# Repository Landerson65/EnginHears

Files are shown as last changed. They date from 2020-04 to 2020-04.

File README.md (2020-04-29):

# EnginHears
LCBC Hearing Aid Development Platform

This project intended to develop a low cost, socially destigmatized hearing aid design. Despite hearing loss being so prominent, the average cost of hearing aids is $2,300 per unit, putting hearing aids out of reach of many low- to middle-income families. In addition, many people who need and can afford hearing aids choose not to buy them, as their bulky aesthetic increases social stigma. To combat these current market limitations, the EnginHears developed a Low Cost Bone Conduction (LCBC) Hearing Aid Development Platform.

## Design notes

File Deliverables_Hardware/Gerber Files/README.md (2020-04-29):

This folder contains all of the necessary files in order
to have the hardware system printed circuit board manufactured. 
This includes drill files, copper layers, silkscreen layers,
board profile and more. These gerber files were created using Autodesk Eagle.

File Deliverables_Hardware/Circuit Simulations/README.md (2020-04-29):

This directory contains files describing the proposed analog filter implementations as well as their simulated magnitude plots. 
In addition, plots of the magnitude responses of the transduction components are also included.

Schematics of the proposed analog circuit are available in the Schematics directory.
Plots of the magnitude responses of the proposed analog filter networks, and transduction components are included in the plots directory

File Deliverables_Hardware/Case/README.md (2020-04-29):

This folder contains 3D design files for the LCBC case assembly.

All of the 3D SolidWorks files for the 9th Iteration of the case assembly are in this directory.
Mechanical drawings of the CAD files for the 9th Iteration are in the Drawings directory
STL files necessary to recreate the 9th iteration of the case assembly (ready for 3D printing) are available in the STL directory.

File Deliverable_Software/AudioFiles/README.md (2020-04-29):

EnginHears
LCBC Hearing Aid Development Platform

In this folder you can find audio files used to test the effectiveness
of the ski-slope filter

_Filtered is added to files post-filtering
and
_50 indicates the max gain was set to 50

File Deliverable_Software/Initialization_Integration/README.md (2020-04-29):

This folder only included the main C file used to test the initializations 
for the microcontroller. It contains a simple notch filter that filters out signal noise.
This is the file that was run in the demo of 
hardware and software integration. To run this file, replace 'watchdog_cpu01.c' 
with this file in the 
Microcontroller_IO folder. They require the same additional libraries.

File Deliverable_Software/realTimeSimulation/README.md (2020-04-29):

This folder contains the MATLAB simulation for real-time filtering applications. 
This simulation was mainly used for debugging purposes as a way to test noise, but
it does show the filter applied in real-time.

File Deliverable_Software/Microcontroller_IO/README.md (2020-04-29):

This folder houses the initialization code needed to make the microcontroller operational.

'watchdog_cpu01.c' is the main file that has the I/O initializations and the general layout
for the filter implementation. The gain calculation is included in this file, but requires
the addition of an FFT/iFFT and DMA to be operational.

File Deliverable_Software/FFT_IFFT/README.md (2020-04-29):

This folder contains the Visual Studio Project Solution that includes the modular C functions.

Example implementations of an FFT, iFFT, and ski-slope filter 
are demonstrated and output to the console.

The example input data was selected because they had known FFT values,
ensuring the FFT algorith operated correctly.

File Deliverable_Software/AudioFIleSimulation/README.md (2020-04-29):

This is a MATLAB simulation that demonstrates adding the ski-slope filtering algorithm 
on conversations that simulate hearing loss.

The file 'enginHearDemo.m' is the main file to run the simulation.
The conversations pre- and post- filtering will be played aloud.

Several graphs analyzing the characteristics of the signal will be output for analysis.

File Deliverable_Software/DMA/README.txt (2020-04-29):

DMA Setup
Team: EnginHears 
Project: Low-Cost Bone-Conduction Hearing Aid
4/29/2020

There are multiple files associated with this project, which have been consolidated into 3 sets

1.  adc_soc_continuous_dma_cpu01.c
2.  buffdac_sine_dma_cpu01.c
3.  DMA_custom_setup.c

**HOW TO RUN*******************************************************************

To run, open up the adc_soc_continuous_dma folder in Code Composer Studio with target device 
TMS320F28377S selected. The main file to run is adc_soc_continuous_dma_cpu01.c.

**CURRENT STATUS**************************************************************

Due to COVID-19 and the lack of F28377s microcontrollers, the DMA setup has not been tested. This document
discusses relevent example files to set up DMA, as well as the final desired set-up below.

The team wants DMA to conduct ACD and DAC via the hardware. 
The peripheral interrupt trigger source is ADCAINT1.
Set up PIE for DMA (PIE INT 7.1)
There will be 3 buffers that are length 128 samples.
The buffers will be used to store ADC samples, filter computations, and DAC output.
The buffers will rotate location in the dmaISR.

**NEXT STEPS******************************************************************

1. Edit the adc_soc_continuous_dma to have the following characteristics
       -Fs = 25,000 Hz
       -Buffer size 128
       -Remove initialization associated with ADC Interrupt and EPWM source
       -Use the DMA_custom_setup.c values as desired reference

2. Once this is working, integrate it into the LOCO BOCO initialization files to get ADC
   working and buffers rotating in the dmaISR.

3. Extend DMA to work on the DAC, using the previous DMA initialization and buffdac_sine_dma_cpu01.c
   as reference.

**adc_soc_continuous_dma_cpu01.c**********************************************

An example script from C2000Ware with supporting folder files that sets up two ADC channels to convert simultaneously. The
results will be transferred by the DMA into a buffer in RAM.

This file contains the desired DMA initialization as well as dmaISR and memory storage.

**buffdac_sine_dma_cpu01.c****************************************************

An example script from C2000Ware with supporting folder files that generates a sine wave on the buffered DAC output using the DMA 
to transfer sine values stored in a sine table in GSRAM to DACVALS, DACOUTA/ADCINA0.

This script is for DAC initialization reference only. However, try to follow the adc_soc_continuous_dma.c format whenever possible.

**DMA_custom_setup.c*********************************************************

This file does not compile. These HAL variable values are for reference only for desired final values.

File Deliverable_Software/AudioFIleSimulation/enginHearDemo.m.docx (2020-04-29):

% EnginHears Version 2.0

%{

I'm calling this version 2.0 even though there was no official version

1.0. I'm treating the algorithm that changed the frequency spectru in

a specific band as version 1.0. Version 2.0 uses the ski-slope filter

that we found online in hearingAidF.m. If a nother significant change

to the algorithm occurs, we'll call that Version 3.0 and so on. Version

2.0 also includes other functions: createPowerSpectrum, viewAudio, and

controlVolume.

%}

%% x = original audio signal

%% Fs = sample rate in Hertz

%% L = number of samples

%% X = the fft of x

%% transitionV = a vector of 4 frequencies used for the calcualtion of the ski-slope filter in freqshape

%% gain = input gainused for the max value in freqshape

%% Xleft_editted = is a variable used to make the application of the filter easier

%% Xright_editted = is a variable used to make the application of the filter easier

%% y = the ifft of the X after the filter is applied

clear; close all;

%% Read and Play Audio File

[x, Fs] = audioread('Conversation-Moderate.mp3');

player = audioplayer( controlVolume(x,1), Fs);

play(player)

pause(50)

%% Take the FFT of the input signal x

X = fft(x);

%% From MATLAB: create Power Spectrum

createPowerSpectrum(X, Fs, ' X')

%% Calculate and Apply Ski-Slope Filter

transitionV = [1000, 1500, 2550, 5000];

g = 50;

[~, gain] = freqshape(x, g, transitionV, Fs); % freqshape claims to adjust

% the signal for you, but the output is not changed noticeably, so I have

%elected to apply the filter manually

Xleft_editted = X(:,1).*gain;

Xright_editted = X(:,2).*gain;

X_editted = cat(2,Xleft_editted,Xright_editted);

%% take the ifft of the editted X signal

y = ifft(X_editted,'symmetric');

%%write to mps file

audiowrite('Conversation_Moderate_Filtered_50.wav', y, Fs);

%% create audio players for the signals

%play player2 for new sample

player2 = audioplayer(controlVolume(y, 1), Fs);

play(player2)

%%

viewAudio(x,Fs,' Conversation')

viewAudio(y,Fs,' Editted Conversation')

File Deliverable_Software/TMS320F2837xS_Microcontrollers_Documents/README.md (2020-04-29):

This folder contains the TMS320F2837xS Microcontrollers datasheet 
For more information on the board visit: 

https://www.ti.com/product/TMS320F28377S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

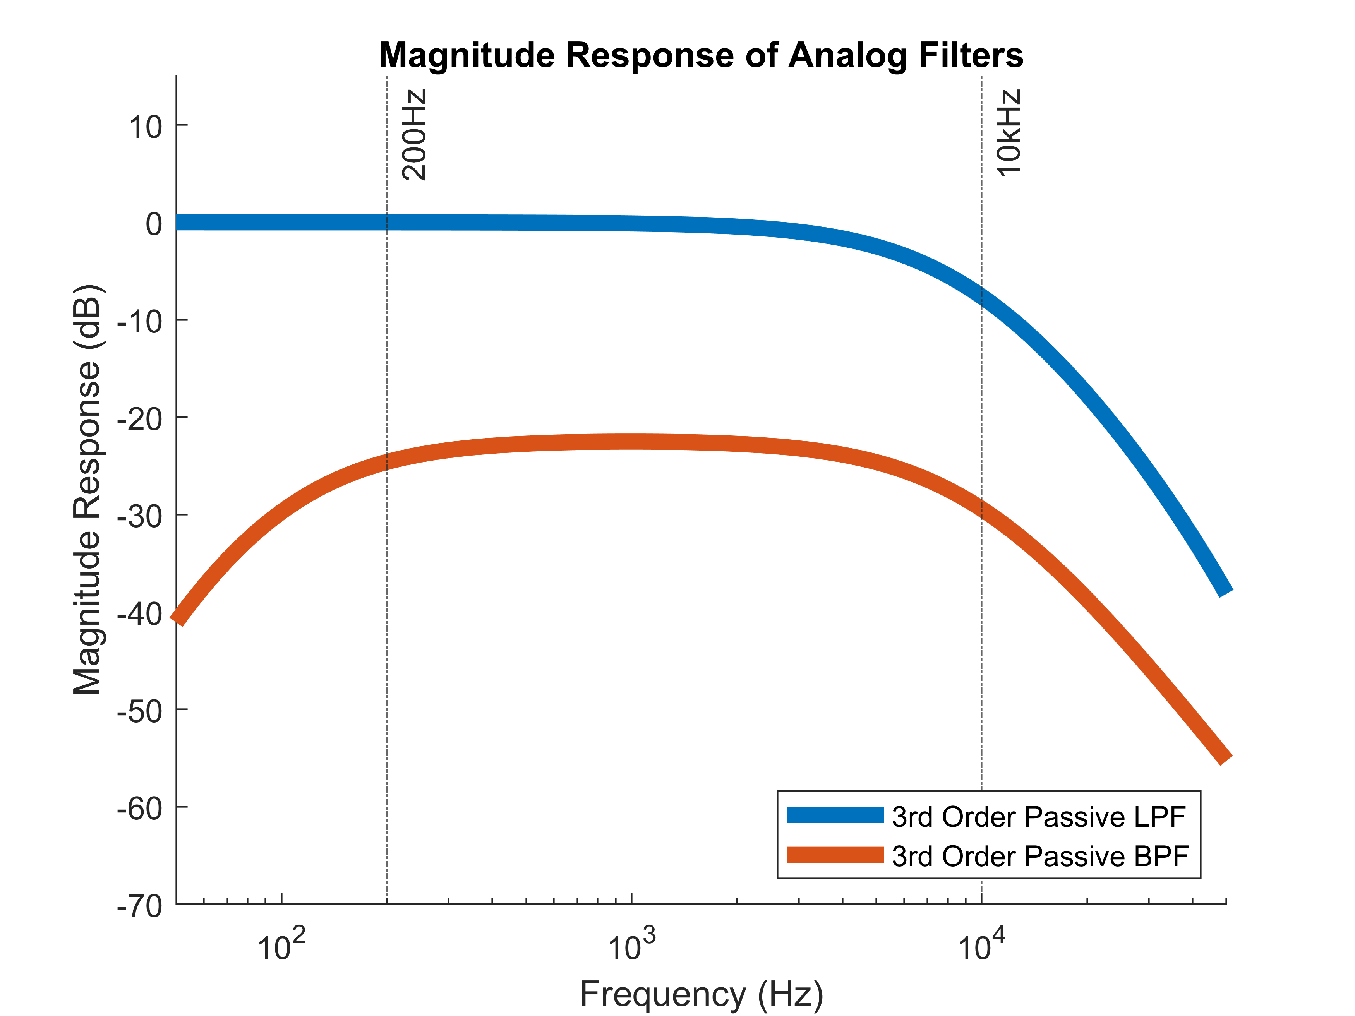
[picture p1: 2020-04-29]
Deliverables_Hardware/Circuit Simulations/Plots/analog_filter_magnitude_plot.png

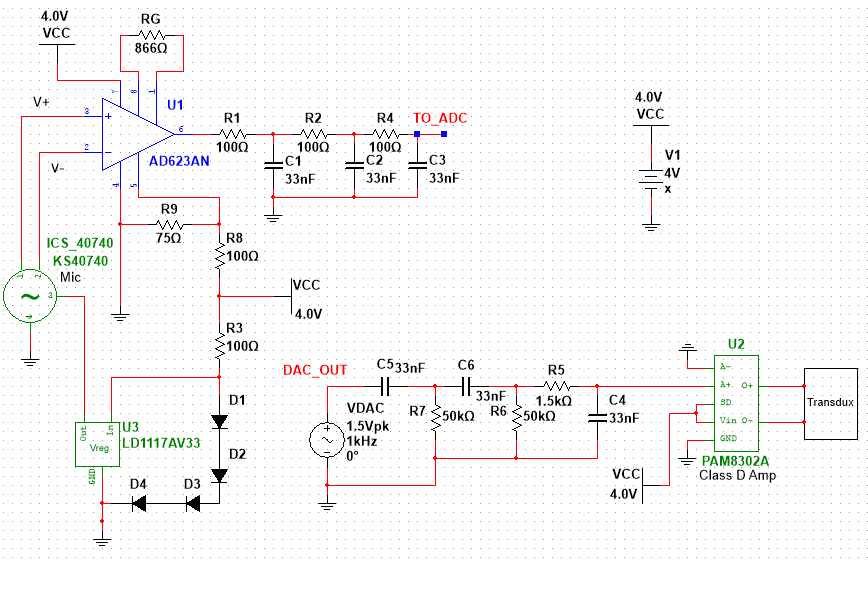
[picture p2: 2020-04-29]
Deliverables_Hardware/Circuit Simulations/Schematics/locoboco_analog_schematic.png

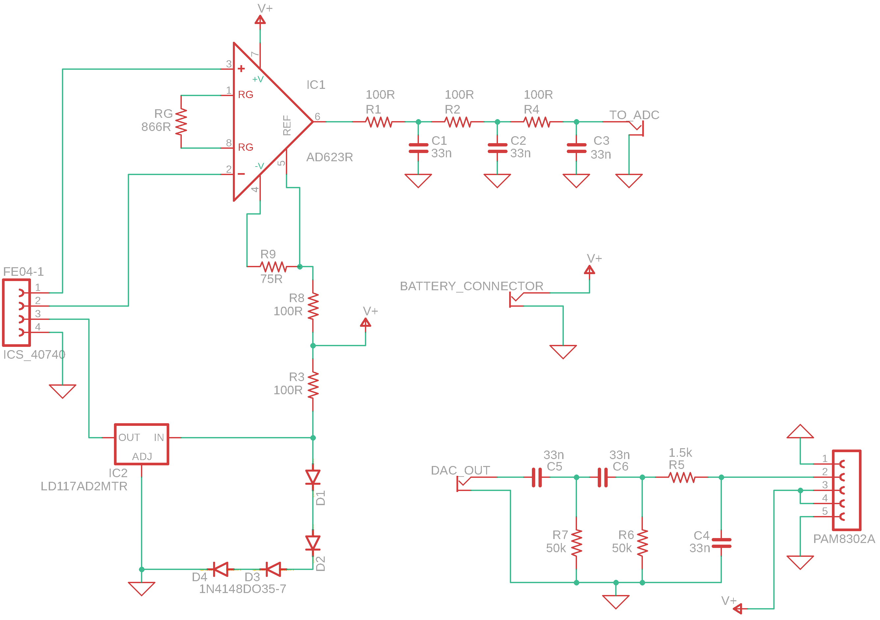
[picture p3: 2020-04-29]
Deliverables_Hardware/Gerber Files/Layout Image/Analog_Schematic.png

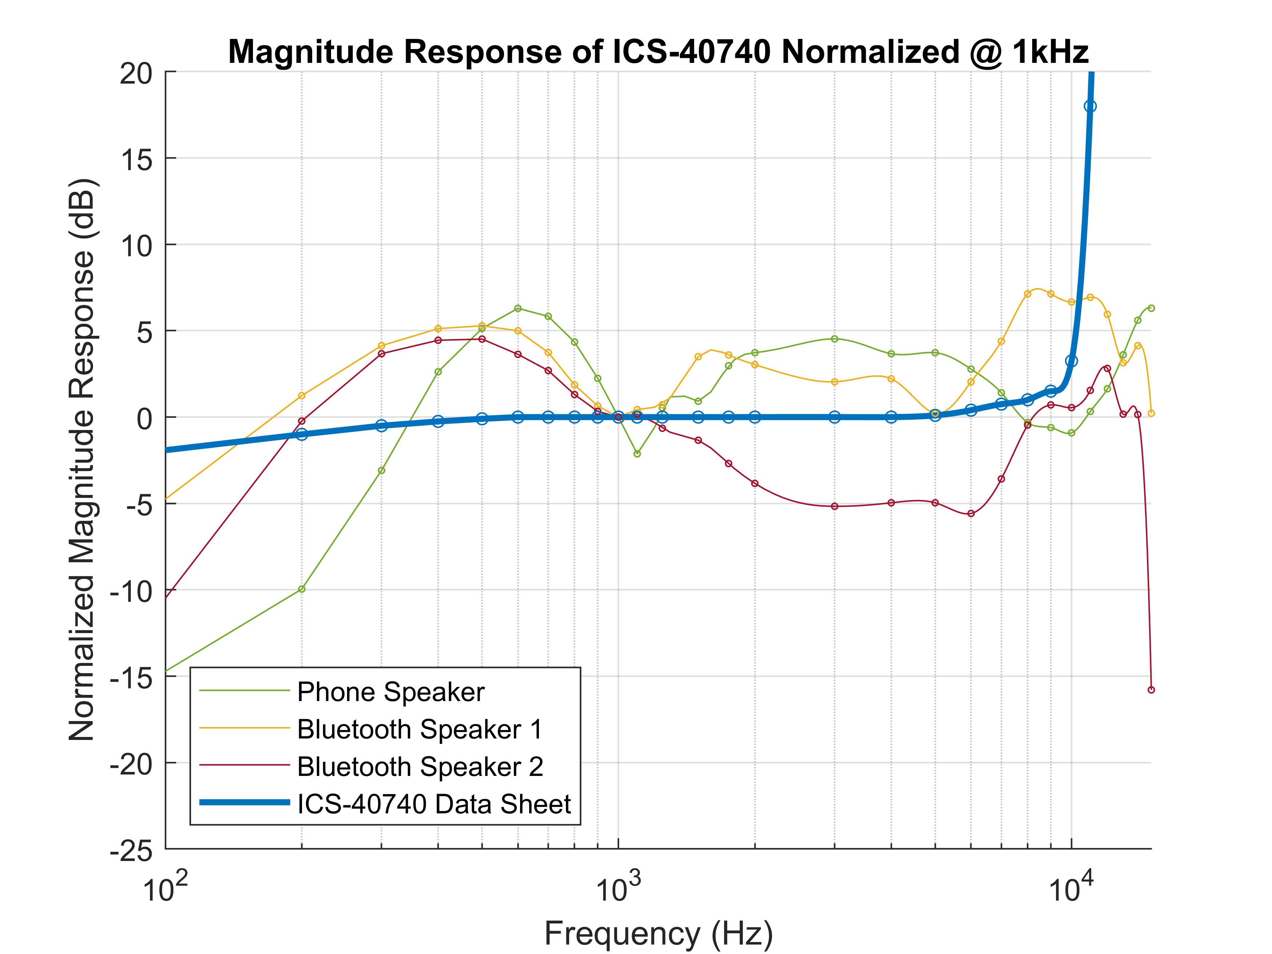
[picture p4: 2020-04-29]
Deliverables_Hardware/Circuit Simulations/Plots/ics-40740_magnitude_response.png

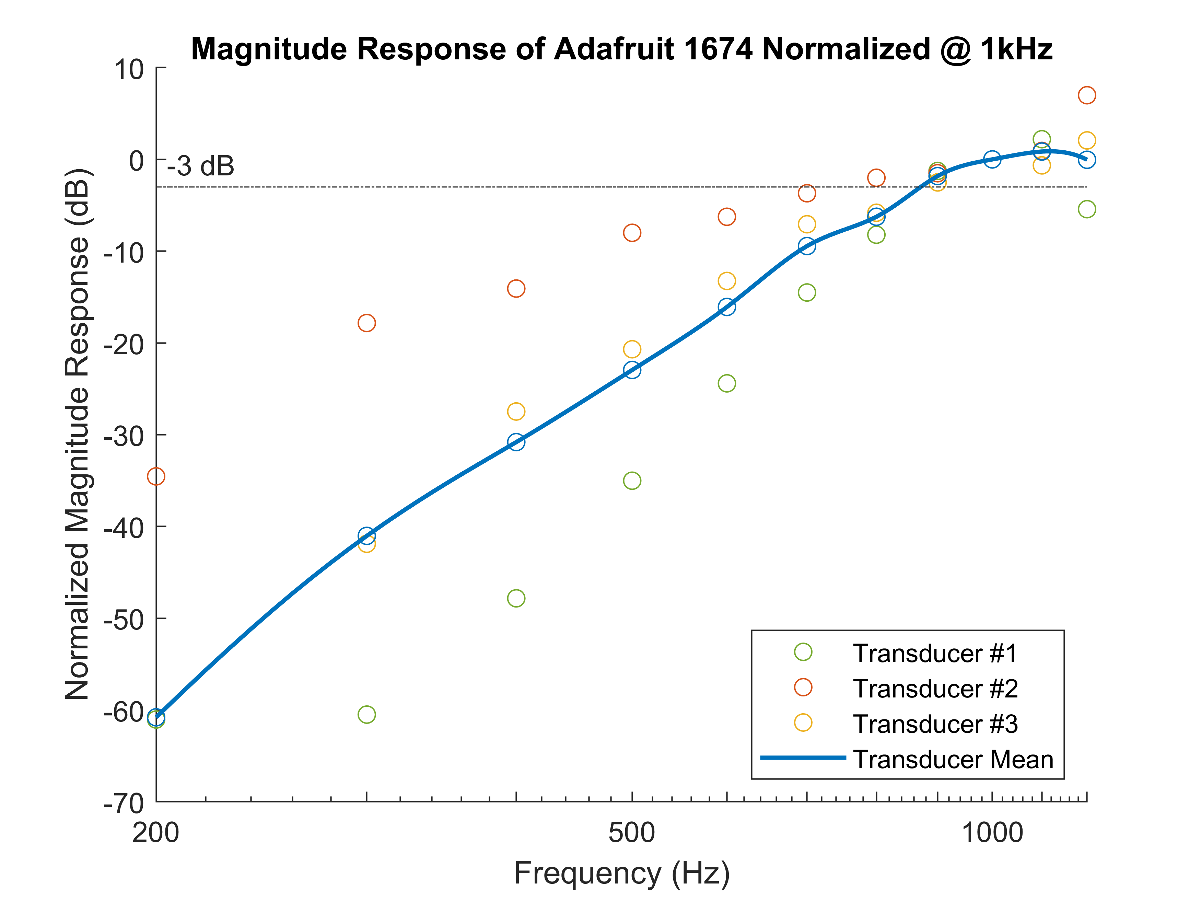
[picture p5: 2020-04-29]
Deliverables_Hardware/Circuit Simulations/Plots/adafruit_1674_bc_transdux_normalized_magnitude_plot.png

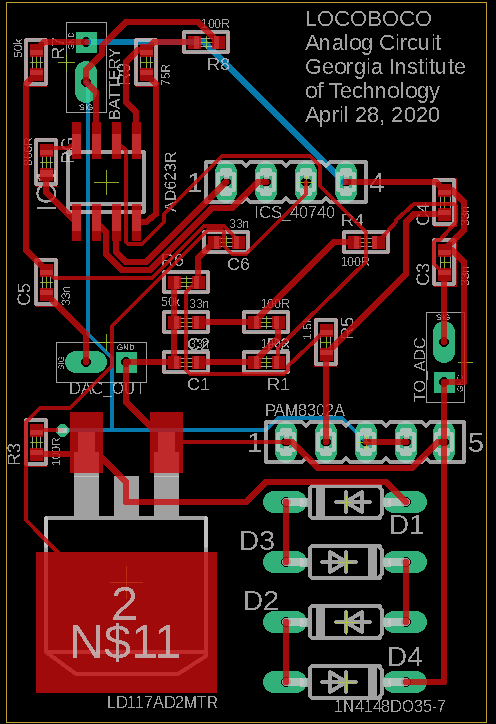
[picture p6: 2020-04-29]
Deliverables_Hardware/Gerber Files/Layout Image/Analog_Circuit_Layout.png

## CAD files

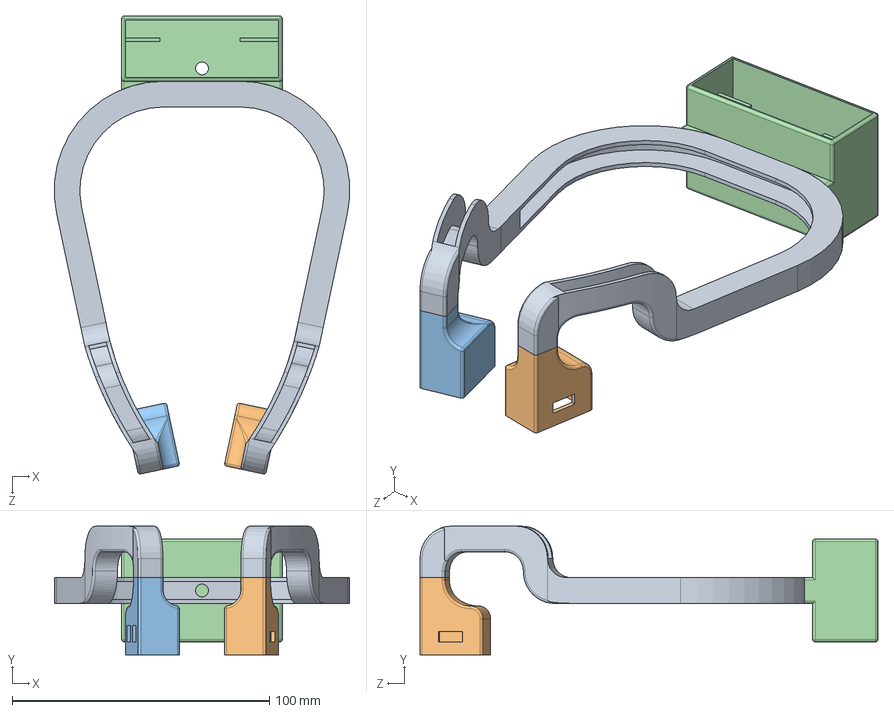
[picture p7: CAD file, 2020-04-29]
Deliverables_Hardware/Case/combined-case-it9.SLDASM
114.8 x 50.0 x 178.1 mm
head-band-it9
transdux-left-it9
transdux-right-it9
elex-compartment-it9

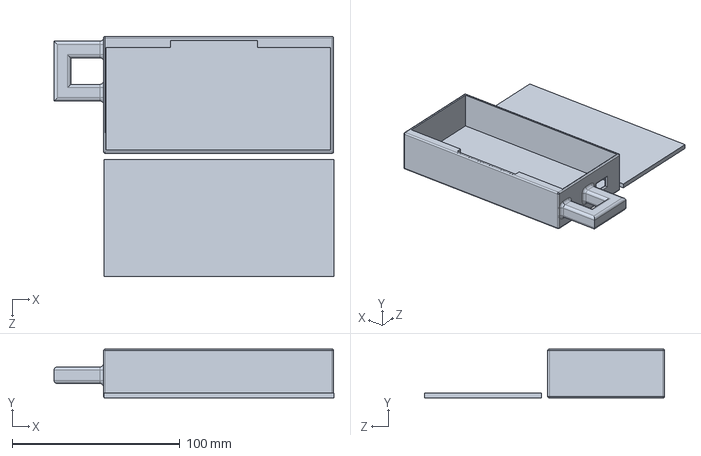
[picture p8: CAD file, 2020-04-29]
Deliverables_Hardware/Case/Box_Belt_Hook_v2.SLDPRT
166.7 x 29.1 x 143.1 mm

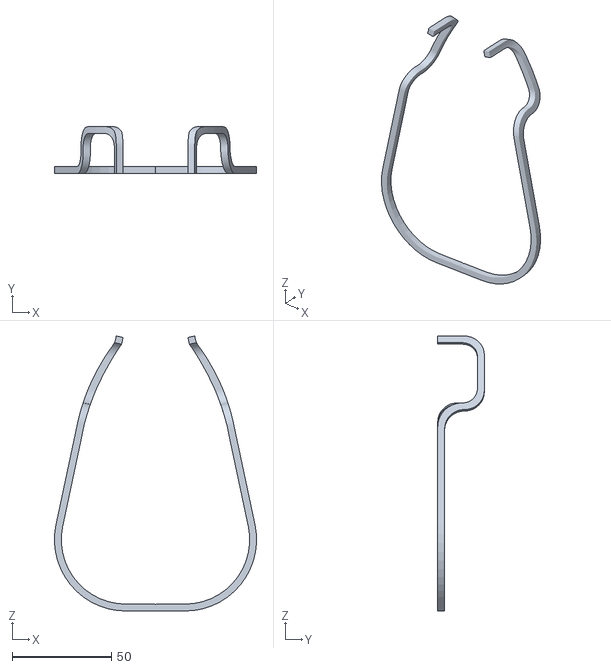
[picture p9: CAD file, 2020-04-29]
Deliverables_Hardware/Case/STL/compression-band-it8_ABS.STL
101.9 x 23.5 x 138.7

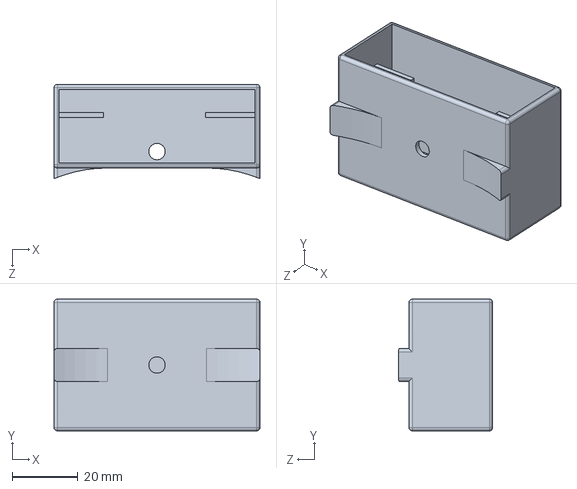
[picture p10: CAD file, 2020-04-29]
Deliverables_Hardware/Case/elex-compartment-it9.SLDPRT
62.5 x 40.0 x 28.6 mm

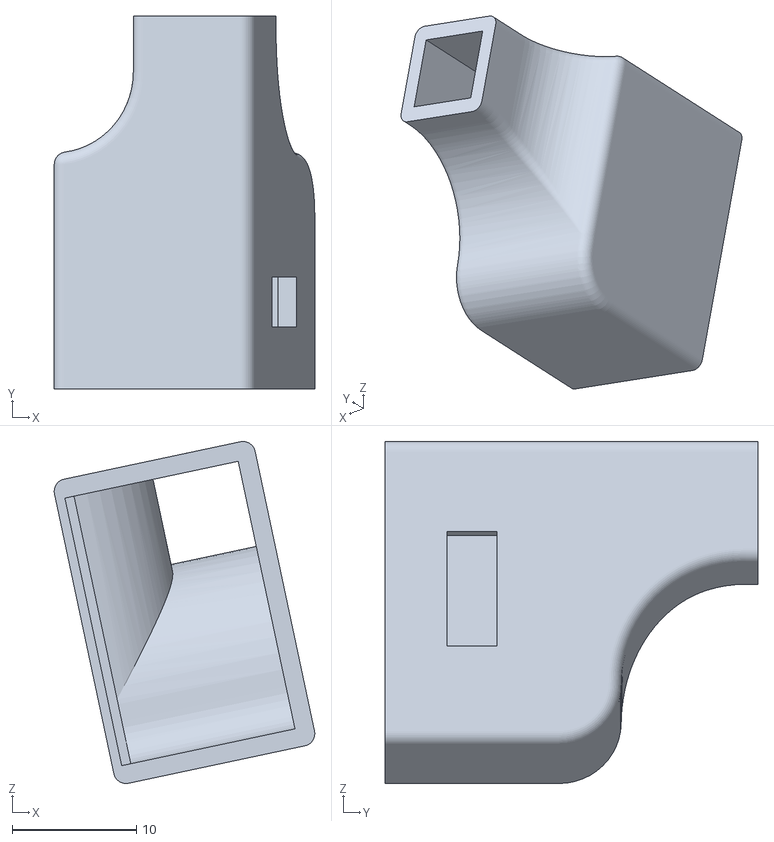
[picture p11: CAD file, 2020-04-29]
Deliverables_Hardware/Case/STL/transdux-left-it9_TPU.STL
21.0 x 30.0 x 27.5

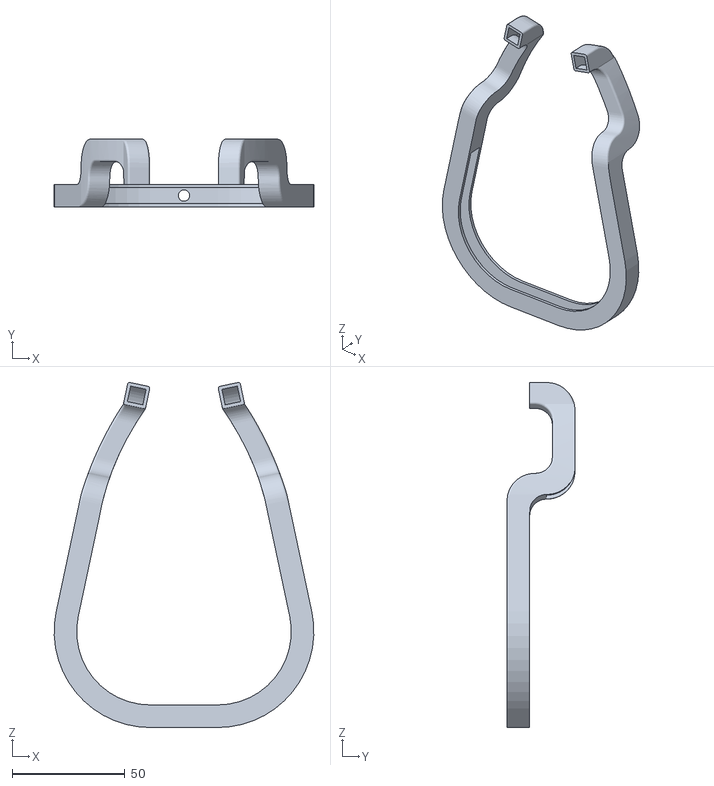
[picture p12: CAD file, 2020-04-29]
Deliverables_Hardware/Case/STL/head-band-it9_TPU.STL
114.9 x 30.0 x 152.7

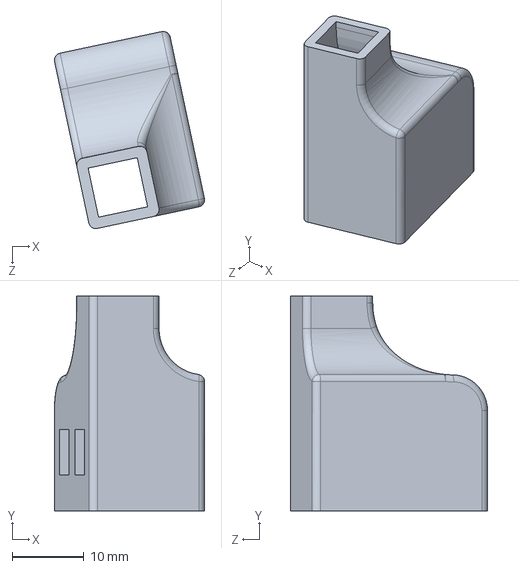
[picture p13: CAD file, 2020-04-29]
Deliverables_Hardware/Case/transdux-right-it9.SLDPRT
21.0 x 30.0 x 27.5 mm

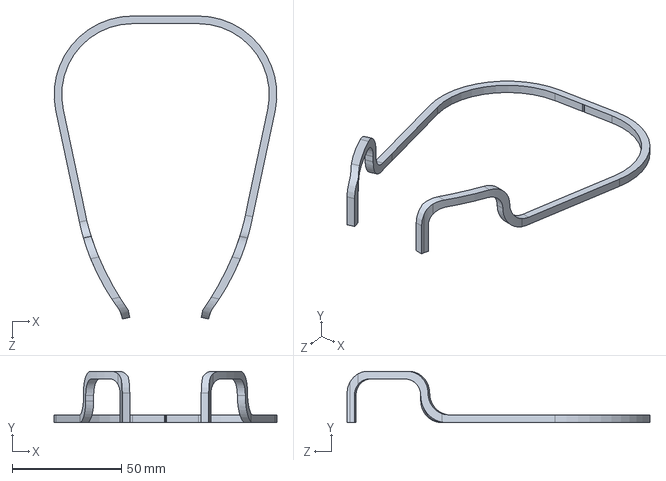
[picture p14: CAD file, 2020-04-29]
Deliverables_Hardware/Case/compression-band-it8.SLDPRT
101.9 x 23.5 x 138.7 mm

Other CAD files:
Deliverable_Software/Microcontroller_IO/cpu01/ccs/CPU1_RAM/F2837xS_Gpio.obj
Deliverable_Software/Microcontroller_IO/cpu01/ccs/CPU1_RAM/F2837xS_SysCtrl.obj
Deliverables_Hardware/Case/STL/elex-compartment-it9_ABS.STL
Deliverable_Software/Microcontroller_IO/cpu01/ccs/CPU1_RAM/watchdog_cpu01.obj
Deliverable_Software/Microcontroller_IO/cpu01/ccs/CPU1_RAM/DelayUs.obj
Deliverable_Software/Microcontroller_IO/cpu01/ccs/CPU1_RAM/F2837xS_CodeStartBranch.obj
Deliverables_Hardware/Case/STL/transdux-right-it9_TPU.STL
Deliverable_Software/Microcontroller_IO/cpu01/ccs/CPU1_RAM/F2837xS_PieCtrl.obj
Deliverables_Hardware/Case/transdux-left-it9.SLDPRT
Deliverable_Software/Microcontroller_IO/cpu01/ccs/CPU1_RAM/F2837xS_usDelay.obj
Deliverable_Software/Microcontroller_IO/cpu01/ccs/CPU1_RAM/F2837xS_DefaultISR.obj
Deliverable_Software/Microcontroller_IO/cpu01/ccs/CPU1_RAM/F2837xS_GlobalVariableDefs.obj
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

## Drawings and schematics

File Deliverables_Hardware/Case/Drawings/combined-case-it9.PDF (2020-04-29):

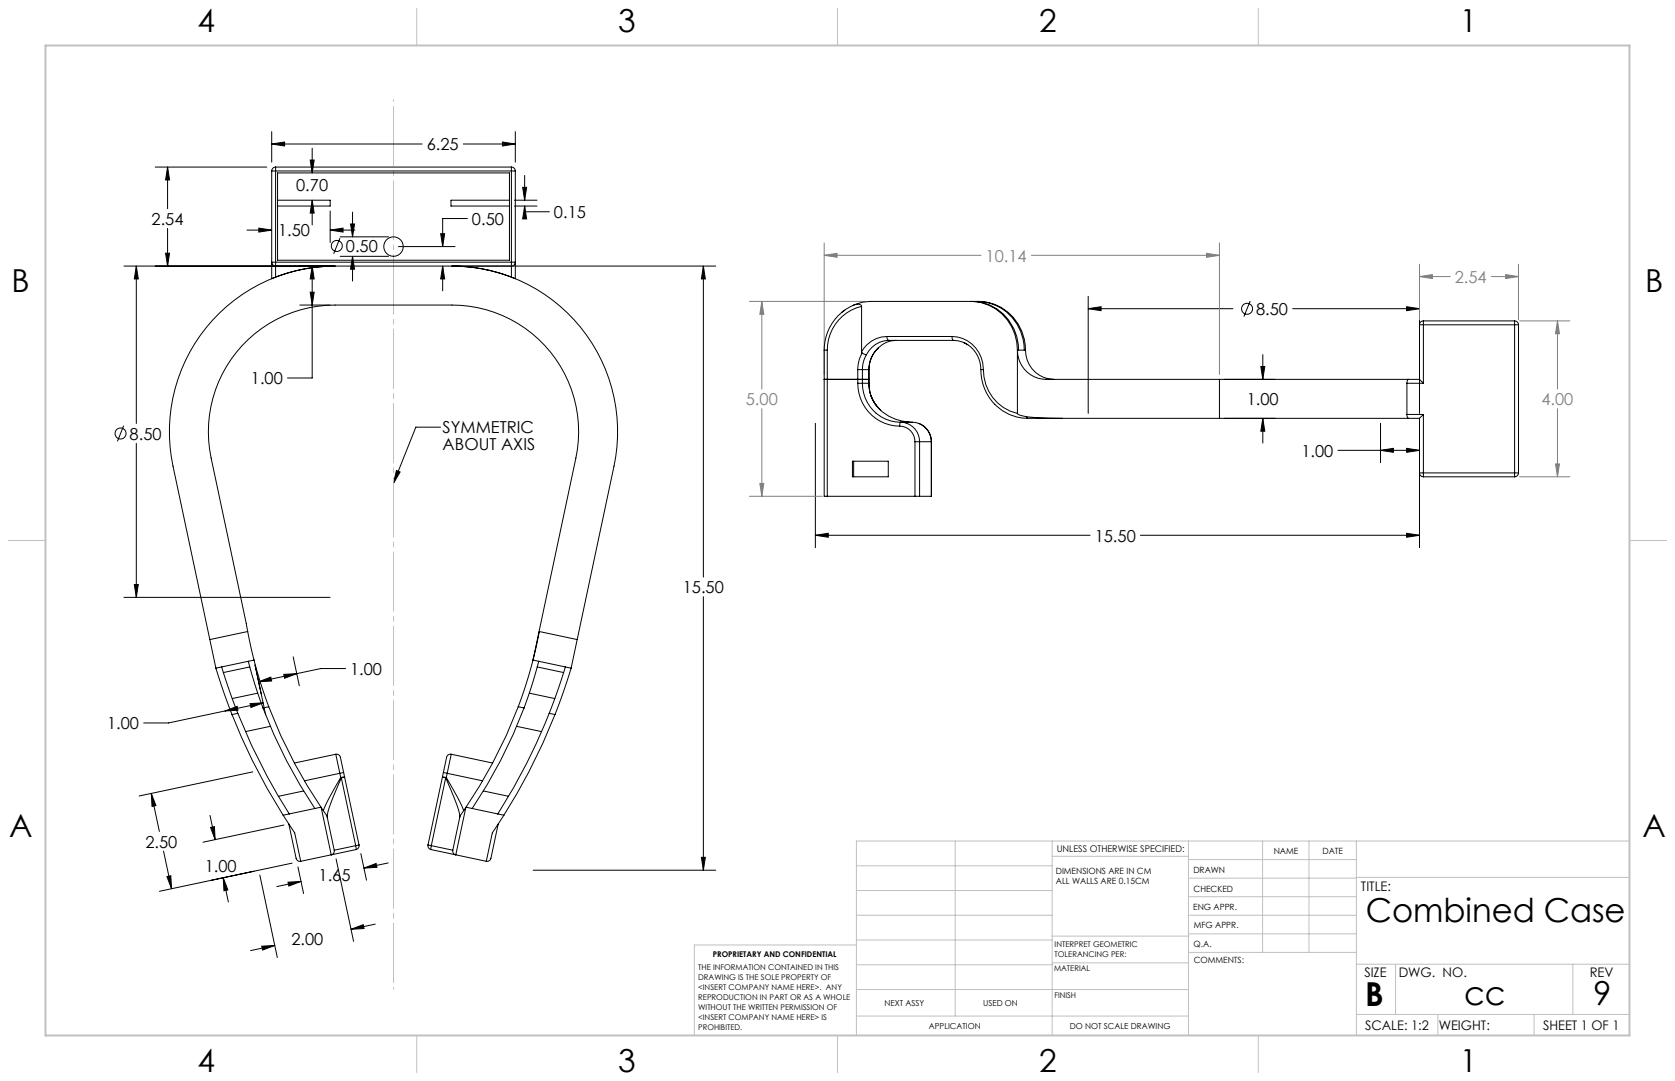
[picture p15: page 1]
ABOUT AXIS

UNLESS OTHERWISE SPECIFIED: | | NAME | DATE
DIMENSIONS ARE IN CM ALL WALLS ARE 0.15CM | DRAWN

CHECKED | | | TITLE: Combined Case

ENG APPR.
MFG APPR.

INTERPRET GEOMETRIC TOLERANCING PER: | Q.A.
MATERIAL | | SIZE B | DWG. NO. cc | REV 9

PROPRIETARY AND CONFIDENTIAL
THE INFORMATION CONTAINED IN THIS
DRAWING IS THE SOLE PROPERTY OF
<INSERT COMPANY NAME HERE>. ANY
REPRODUCTION IN PART OR AS A WHOLE
WITHOUT THE WRITTEN PERMISSION OF
<INSERT COMPANY NAME HERE> IS
PROHIBITED.

NEXT ASSY | USED ON | FINISH

APPLICATION | DO NOT SCALE DRAWING | | SCALE: 1:2 | WEIGHT: | SHEET 1 OF 1

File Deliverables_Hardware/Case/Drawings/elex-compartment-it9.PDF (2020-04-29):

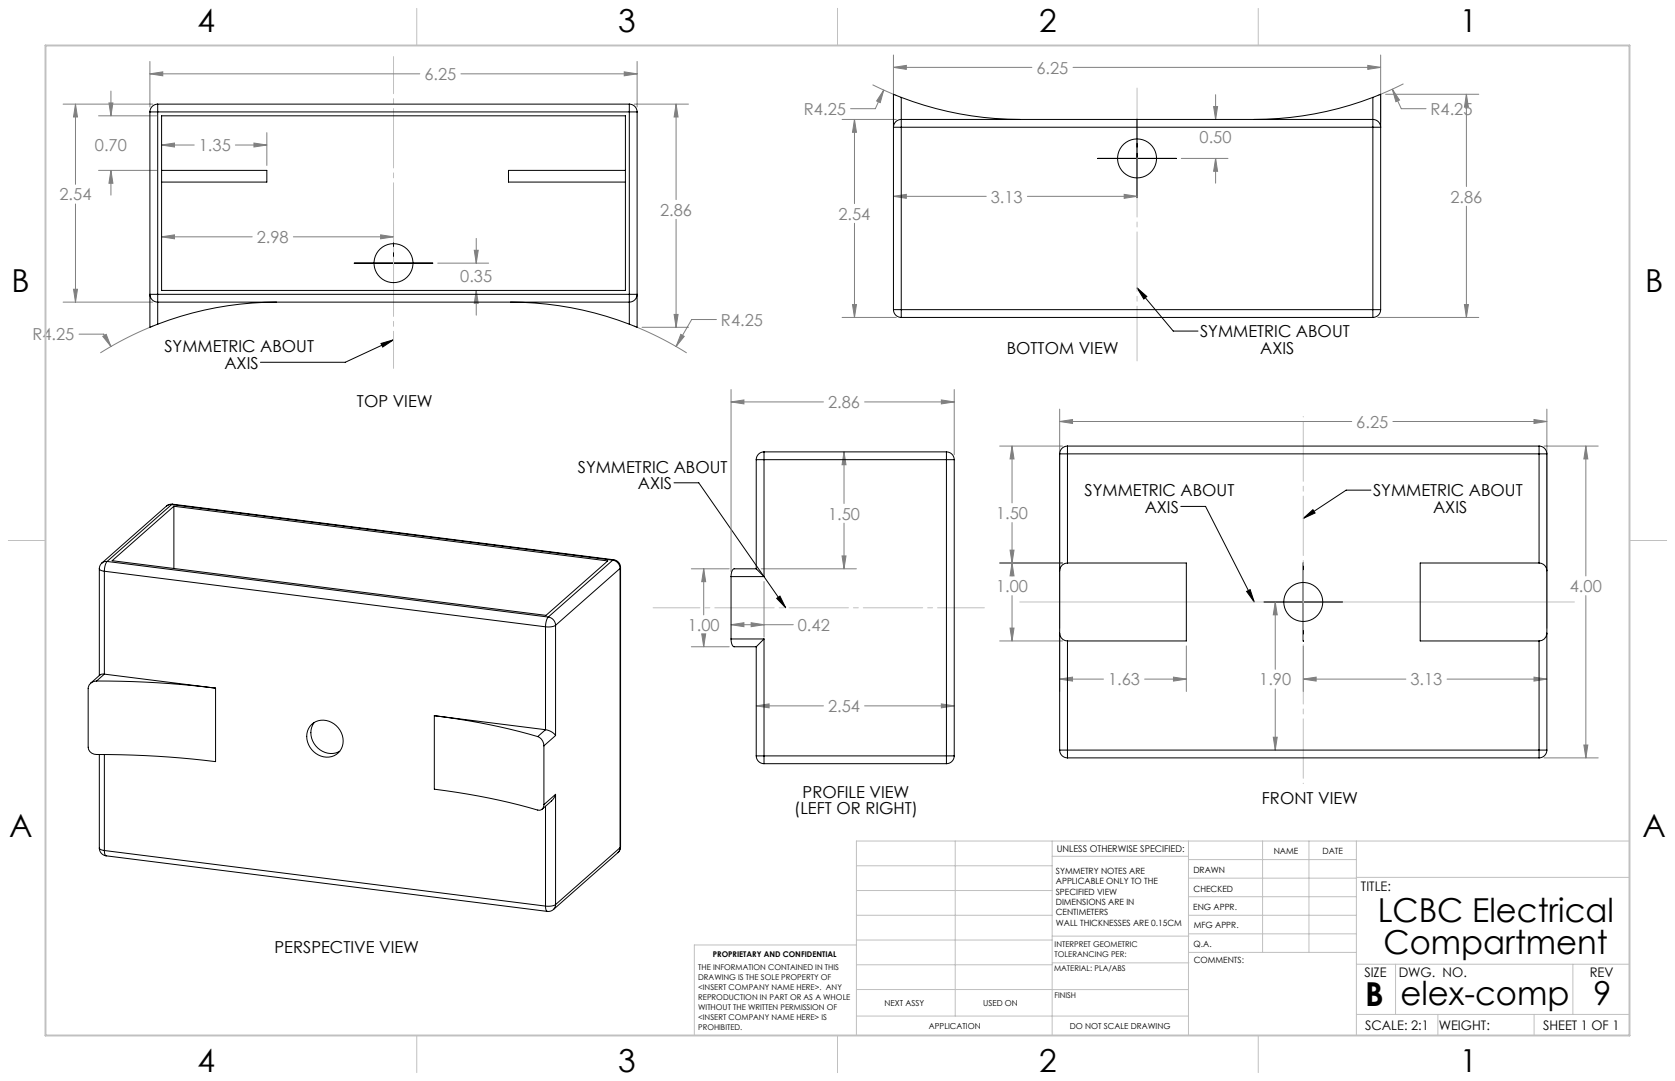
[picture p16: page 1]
SYMMETRIC ABOUT; TOP VIEW; FRONT VIEW; BOTTOM VIEW; AXIS; PERSPECTIVE VIEW

PROFILE VIEW
(LEFT OR RIGHT)

UNLESS OTHERWISE SPECIFIED: | | NAME | DATE
SYMMETRY NOTES ARE APPLICABLE ONLY TO THE SPECIFIED VIEW DIMENSIONS ARE IN CENTIMETERS WALL THICKNESSES ARE 0.15CM | DRAWN

CHECKED | | | TITLE: LCBC Electrical Compartment

ENG APPR.
MFG APPR.

INTERPRET GEOMETRIC TOLERANCING PER: | Q.A.
MATERIAL: PLA/ABS | | SIZE B | DWG. NO. elex-comp | REV 9

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

NEXT ASSY | USED ON | FINISH

APPLICATION | DO NOT SCALE DRAWING | | SCALE: 2:1 | WEIGHT: | SHEET 1 OF 1

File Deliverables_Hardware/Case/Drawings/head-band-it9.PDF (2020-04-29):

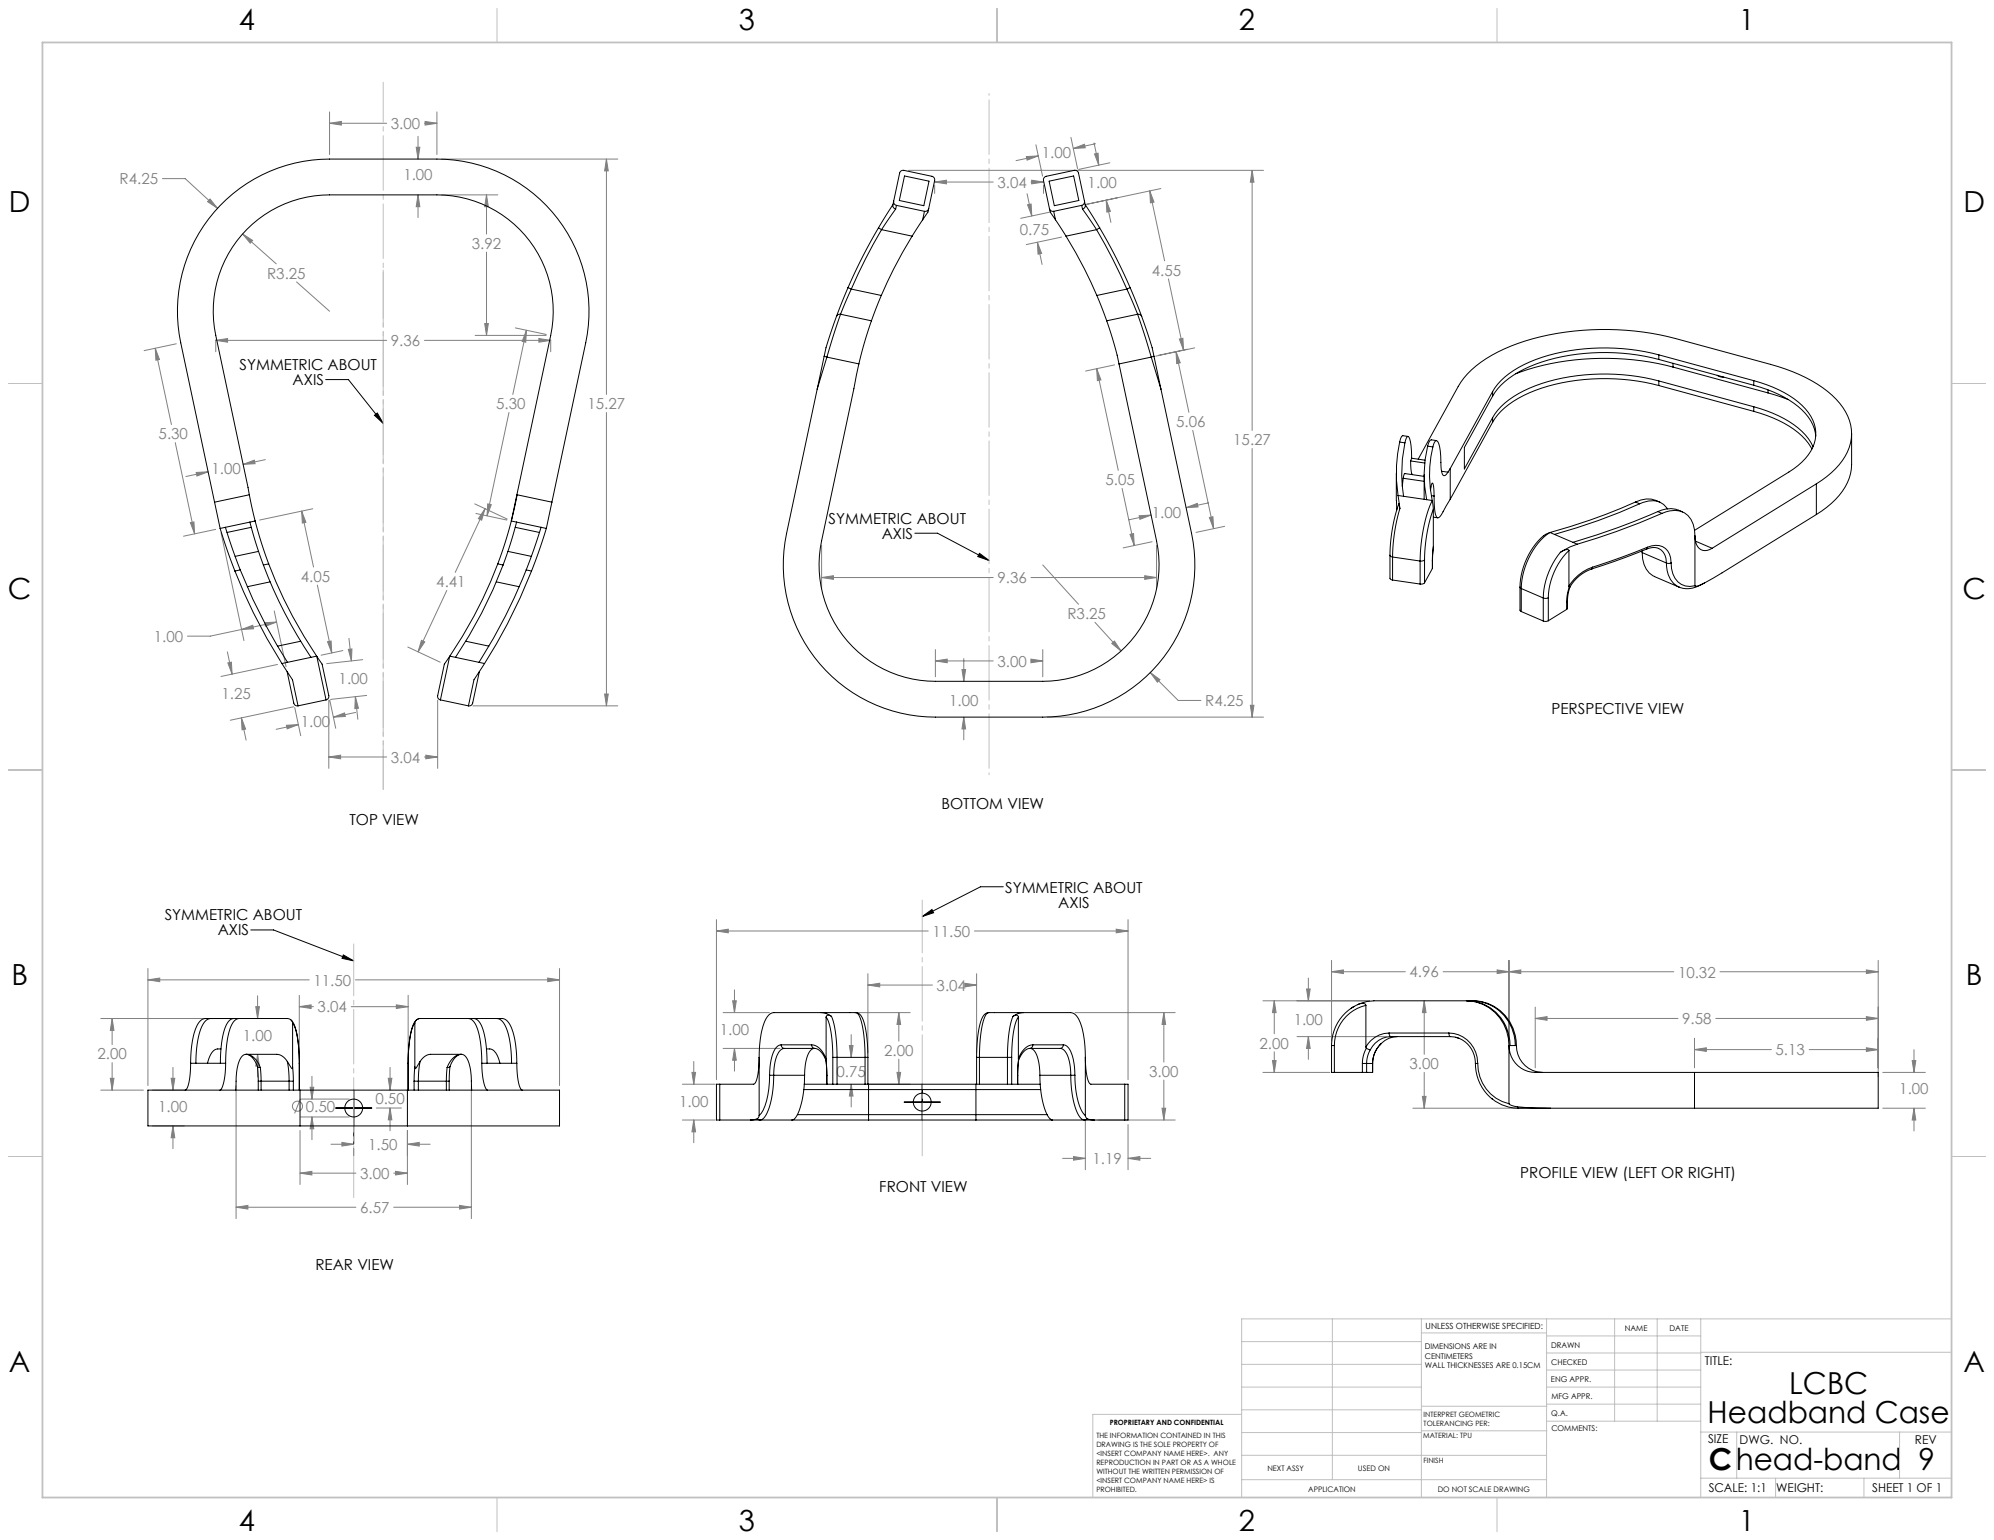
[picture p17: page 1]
SYMMETRIC ABOUT; TOP VIEW; PERSPECTIVE VIEW; BOTTOM VIEW; FRONT VIEW; REAR VIEW

PROFILE VIEW (LEFT OR RIGHT)

UNLESS OTHERWISE SPECIFIED: | | NAME | DATE
DIMENSIONS ARE IN CENTIMETERS WALL THICKNESSES ARE 0.15CM | DRAWN

CHECKED | | | TITLE: LCBC Headband Case

ENG APPR.
MFG APPR.

INTERPRET GEOMETRIC TOLERANCING PER: | Q.A.
MATERIAL: TPU | | SIZE C | DWG. NO. head-band | REV 9

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

NEXT ASSY | USED ON | FINISH

APPLICATION | DO NOT SCALE DRAWING | | SCALE: 1:1 | WEIGHT: | SHEET 1 OF 1

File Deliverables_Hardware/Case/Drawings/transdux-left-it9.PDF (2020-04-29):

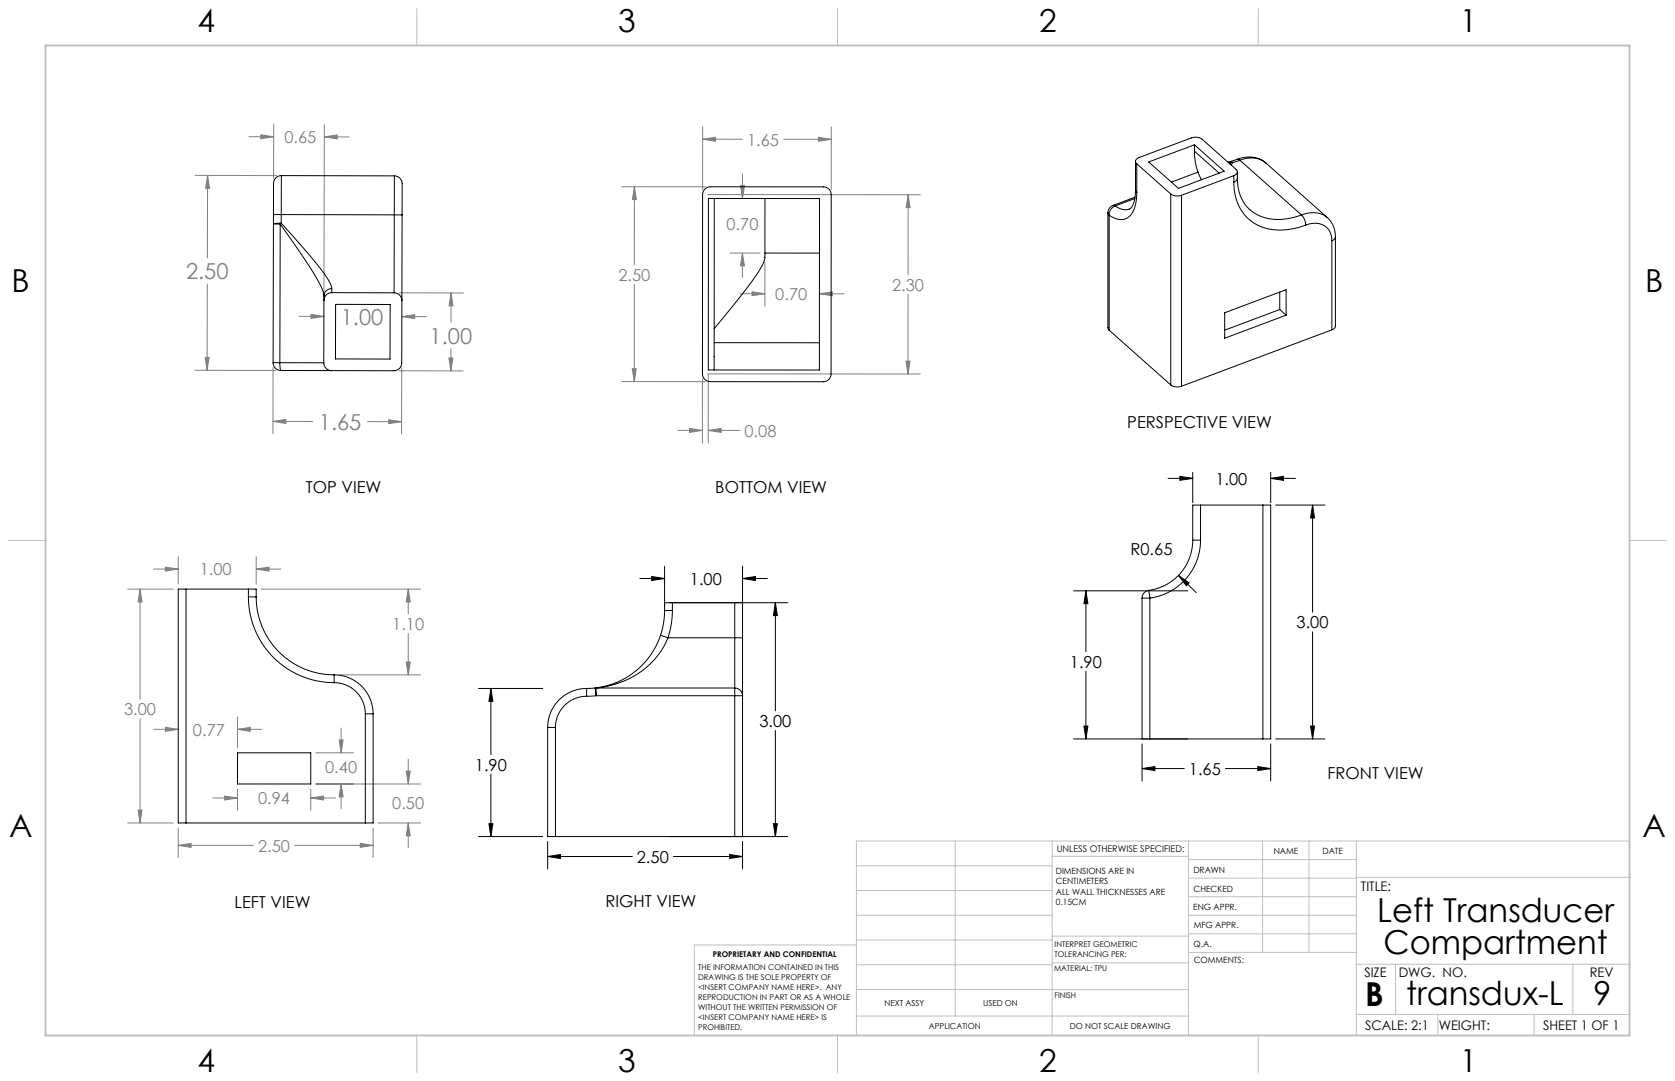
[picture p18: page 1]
TOP VIEW; RIGHT VIEW; BOTTOM VIEW; LEFT VIEW; FRONT VIEW; PERSPECTIVE VIEW

UNLESS OTHERWISE SPECIFIED: | | NAME | DATE
DIMENSIONS ARE IN CENTIMETERS ALL WALL THICKNESSES ARE 0.15CM | DRAWN

CHECKED | | | TITLE: Left Transducer Compartment

ENG APPR.
MFG APPR.

INTERPRET GEOMETRIC TOLERANCING PER: | Q.A.
MATERIAL: TPU | | SIZE B | DWG. NO. transdux-L | REV 9

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

NEXT ASSY | USED ON | FINISH

APPLICATION | DO NOT SCALE DRAWING | | SCALE: 2:1 | WEIGHT: | SHEET 1 OF 1

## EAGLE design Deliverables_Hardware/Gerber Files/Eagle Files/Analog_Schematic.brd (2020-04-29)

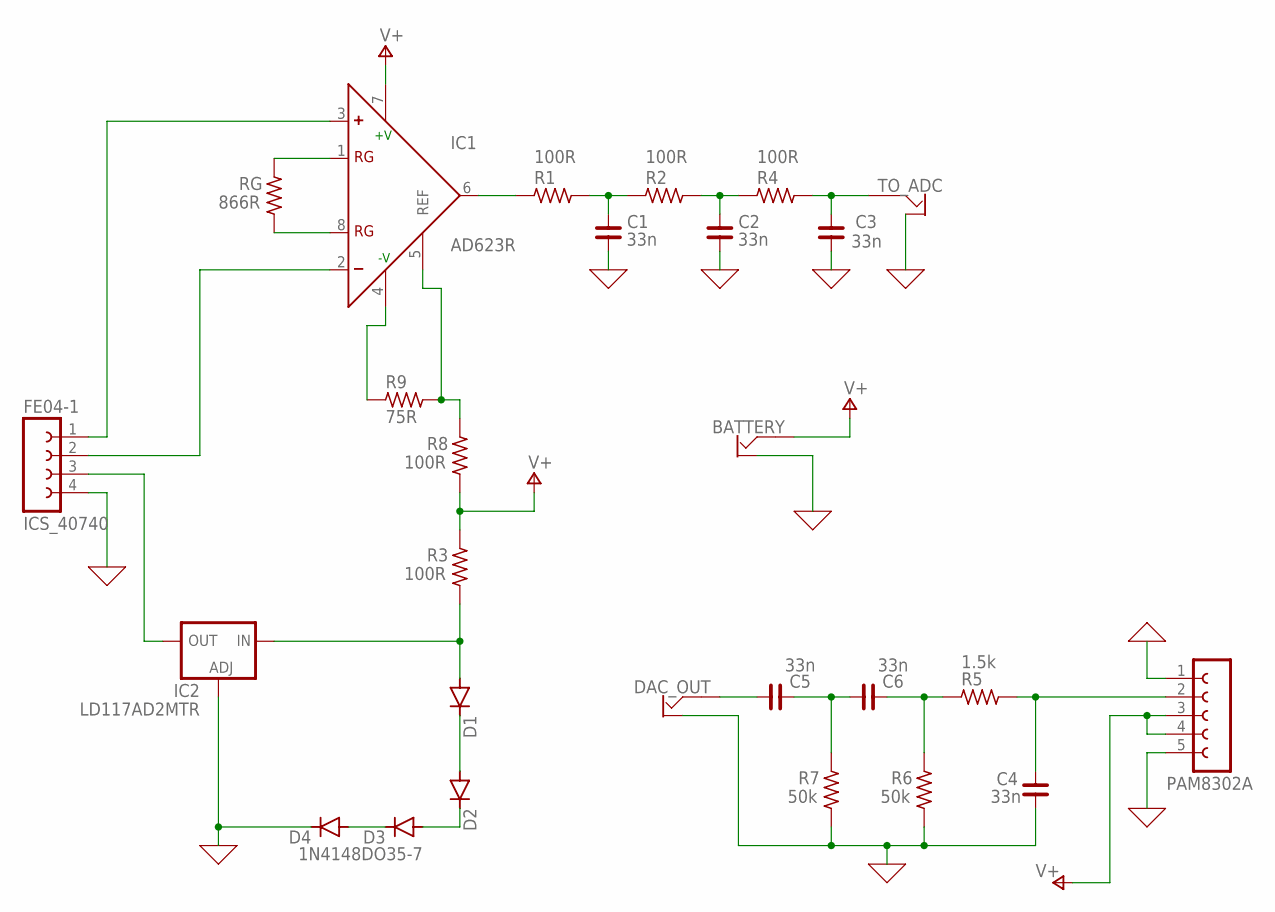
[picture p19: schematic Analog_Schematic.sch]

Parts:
BATTERY: OFFBOARD2JACKALT
C1, C2, C3, C4, C5, C6: 33n; C0603
D1, D2, D3, D4: 1N4148DO35-7; DO35-7
DAC_OUT: OFFBOARD2JACKALT
IC1: AD623R; SO8
IC2: LD117AD2MTR; D2PACK
ICS_40740: FE04-1
PAM8302A: FE05-1
R1, R2, R3, R4, R8: 100R; R0603
R5: 1.5k; R0603
R6, R7: 50k; R0603
R9: 75R; R0603
RG: 866R; R0603
TO_ADC: OFFBOARD2JACKALT

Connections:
0: BATTERY.GND, C1.2, C2.2, C3.2, C4.2, D4.C, DAC_OUT.GND, IC2.1 (ADJ), ICS_40740.4, PAM8302A.1, PAM8302A.5, R6.1, R7.1, TO_ADC.GND
unnamed: IC1.8 (RG), RG.1
unnamed: IC1.1 (RG), RG.2
unnamed: IC1.6 (OUT), R1.1
unnamed: IC1.4 (-V), R9.1
unnamed: IC1.5 (REF), R8.2, R9.2
unnamed: D1.A, IC2.3 (IN), R3.1
unnamed: D1.C, D2.A
unnamed: D2.C, D3.A
unnamed: D3.C, D4.A
unnamed: IC2.2 (OUT), ICS_40740.3
unnamed: IC1.3 (+), ICS_40740.1
unnamed: IC1.2 (-), ICS_40740.2
unnamed: C1.1, R1.2, R2.1
unnamed: C2.1, R2.2, R4.1
unnamed: C3.1, R4.2, TO_ADC.SIGNAL
unnamed: C5.1, DAC_OUT.SIGNAL
unnamed: C5.2, C6.1, R7.2
unnamed: C6.2, R5.1, R6.2
unnamed: C4.1, PAM8302A.2, R5.2
V+: BATTERY.SIGNAL, IC1.7 (+V), PAM8302A.3, PAM8302A.4, R3.2, R8.1

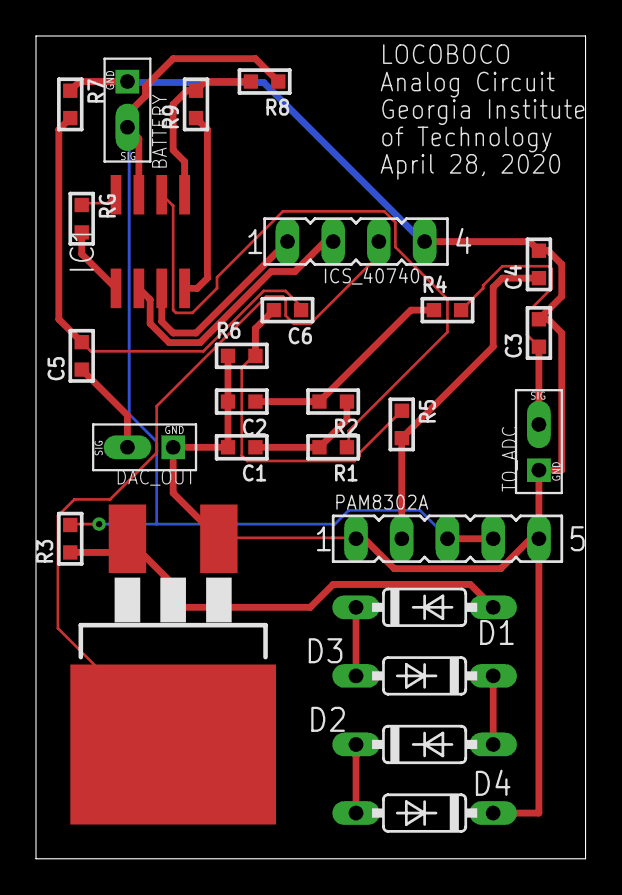
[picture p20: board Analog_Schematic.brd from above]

Board: 2 copper layers, 30.5 x 45.7 mm, 27 parts (0 on the bottom side), 21 nets.

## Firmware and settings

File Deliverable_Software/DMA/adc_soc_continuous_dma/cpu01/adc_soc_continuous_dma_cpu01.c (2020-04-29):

//###########################################################################
//
// FILE:   adc_soc_continuous_dma_cpu01.c
//
// TITLE:  ADC continuous conversions read by DMA for F2837xS.
//
//! \addtogroup cpu01_example_list
//! <h1> ADC Continuous Conversions Read by DMA (adc_soc_continuous_dma)</h1>
//!
//! This example sets up two ADC channels to convert simultaneously. The
//! results will be transferred by the DMA into a buffer in RAM.
//!
//! After the program runs, the memory will contain:
//!
//! - \b adcData0 \b: a digital representation of the voltage on pin A3\n
//! - \b adcData1 \b: a digital representation of the voltage on pin B3\n
//!
//
//###########################################################################
// $TI Release: F2837xS Support Library v3.08.00.00 $
// $Release Date: Mon Dec 23 17:37:14 IST 2019 $
// $Copyright:
// Copyright (C) 2014-2019 Texas Instruments Incorporated - http://www.ti.com/
//
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
//   Redistributions of source code must retain the above copyright 
//   notice, this list of conditions and the following disclaimer.
// 
//   Redistributions in binary form must reproduce the above copyright
//   notice, this list of conditions and the following disclaimer in the 
//   documentation and/or other materials provided with the   
//   distribution.
// 
//   Neither the name of Texas Instruments Incorporated nor the names of
//   its contributors may be used to endorse or promote products derived
//   from this software without specific prior written permission.
// 
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
//
// Included Files
//
#include "F28x_Project.h"

//
// Function Prototypes
//
__interrupt void adca1_isr(void);
__interrupt void dmach1_isr(void);

void ConfigureEPWM(void);
void ConfigureADC(void);
void SetupADCContinuous(volatile struct ADC_REGS * adcRegs, Uint16 channel);
void DMAInit(void);

//
// Defines
//
#define RESULTS_BUFFER_SIZE 1024    // Buffer for storing conversion results
                                    // (size must be multiple of 16)

//
// Globals
//
#pragma DATA_SECTION(adcData0, "ramgs0");
#pragma DATA_SECTION(adcData1, "ramgs0");
Uint16 adcData0[RESULTS_BUFFER_SIZE];
Uint16 adcData1[RESULTS_BUFFER_SIZE];
volatile Uint16 done;

void main(void)
{
    Uint16 resultsIndex;

//
// Step 1. Initialize System Control:
// PLL, WatchDog, enable Peripheral Clocks
// This example function is found in the F2837xS_SysCtrl.c file.
//
    InitSysCtrl();

//
// Step 2. Initialize GPIO:
// This example function is found in the F2837xS_Gpio.c file and
// illustrates how to set the GPIO to it's default state.
//
    InitGpio();

//
// Step 3. Clear all interrupts and initialize PIE vector table:
// Disable CPU interrupts
//
    DINT;

//
// Initialize the PIE control registers to their default state.
// The default state is all PIE interrupts disabled and flags
// are cleared.
// This function is found in the F2837xS_PieCtrl.c file.
//
    InitPieCtrl();

//
// Disable CPU interrupts and clear all CPU interrupt flags:
//
    IER = 0x0000;
    IFR = 0x0000;

//
// Initialize the PIE vector table with pointers to the shell Interrupt
// Service Routines (ISR).
// This will populate the entire table, even if the interrupt
// is not used in this example.  This is useful for debug purposes.
// The shell ISR routines are found in F2837xS_DefaultIsr.c.
// This function is found in F2837xS_PieVect.c.
//
    InitPieVectTable();

//
// Set up ISRs used by this example
//
// ISR for ADCA INT1 - occurs after first conversion
// ISR for DMA ch1 - occurs when DMA transfer is complete
//
    EALLOW;
    PieVectTable.ADCA1_INT = &adca1_isr;
    PieVectTable.DMA_CH1_INT = &dmach1_isr;
    EDIS;

//
// Enable specific CPU interrupts: INT1 for ADCs and INT7 for DMA
//
    IER |= M_INT1;
    IER |= M_INT7;

//
// Enable specific PIE interrupts
//
// ADCA INT1 - Group 1, interrupt 1
// DMA interrupt - Group 7, interrupt 1
//
    PieCtrlRegs.PIEIER1.bit.INTx1 = 1;
    PieCtrlRegs.PIEIER7.bit.INTx1 = 1;

//
// Stop the ePWM clock
//
    EALLOW;
    CpuSysRegs.PCLKCR0.bit.TBCLKSYNC = 0;
    EDIS;

//
// Call the set up function for ePWM 2
//
    ConfigureEPWM();

//
// Start the ePWM clock
//
    EALLOW;
    CpuSysRegs.PCLKCR0.bit.TBCLKSYNC = 1;
    EDIS;

//
// Configure the ADC and power it up
//
    ConfigureADC();

//
// Setup the ADC for continuous conversions on channels A3 and B3
//
    SetupADCContinuous(&AdcaRegs, 3);
    SetupADCContinuous(&AdcbRegs, 3);

//
// Initialize the DMA
//
    DMAInit();

//
// Enable global Interrupts and higher priority real-time debug events:
//
    EINT;  // Enable Global interrupt INTM
    ERTM;  // Enable Global realtime interrupt DBGM

//
// Initialize results buffer
//
    for(resultsIndex = 0; resultsIndex < RESULTS_BUFFER_SIZE; resultsIndex++)
    {
        adcData0[resultsIndex] = 0;
        adcData1[resultsIndex] = 0;
    }

//
// Clearing all pending interrupt flags
//
    EALLOW;

    DmaRegs.CH1.CONTROL.bit.PERINTCLR = 1;
    DmaRegs.CH2.CONTROL.bit.PERINTCLR = 1;
    AdcaRegs.ADCINTFLGCLR.all = 0x3;
    AdcbRegs.ADCINTFLGCLR.all = 0x3;
    EPwm2Regs.ETCNTINITCTL.bit.SOCAINITFRC = 1;
    EPwm2Regs.ETCLR.bit.SOCA = 1;

//
// Enable continuous operation by setting the last SOC to re-trigger the first
//
    AdcaRegs.ADCINTSOCSEL1.bit.SOC0 = 2;
    AdcbRegs.ADCINTSOCSEL1.bit.SOC0 = 2;

    EDIS;

//
// Start DMA
//
    done = 0;
    StartDMACH1();
    StartDMACH2();

//
// Finally, enable the SOCA trigger from ePWM. This will kick off
// conversions at the next ePWM event.
//
    EPwm2Regs.ETSEL.bit.SOCAEN = 1;

//
// Loop until the ISR signals the transfer is complete
//
    while(done == 0)
    {
        __asm(" NOP");
    }
    ESTOP0;
}

//
// adca1_isr - This is called after the very first conversion and will disable
//             the ePWM SOC to avoid re-triggering problems.
//
#pragma CODE_SECTION(adca1_isr, ".TI.ramfunc");
__interrupt void adca1_isr(void)
{
    //
    // Remove ePWM trigger
    //
    EPwm2Regs.ETSEL.bit.SOCAEN = 0;

    //
    // Disable this interrupt from happening again
    //
    PieCtrlRegs.PIEIER1.bit.INTx1 = 0;

    //
    // Acknowledge
    //
    PieCtrlRegs.PIEACK.all = PIEACK_GROUP1;
}

//
// dmach1_isr - This is called at the end of the DMA transfer, the conversions
//              are stopped by removing the trigger of the first SOC from
//              the last.
//
#pragma CODE_SECTION(dmach1_isr, ".TI.ramfunc");
__interrupt void dmach1_isr(void)
{
    //
    // Stop the ADC by removing the trigger for SOC0
    //
    EALLOW;
    AdcaRegs.ADCINTSOCSEL1.bit.SOC0 = 0;
    AdcbRegs.ADCINTSOCSEL1.bit.SOC0 = 0;
    EDIS;

    done = 1;

    //
    // Acknowledge
    //
    PieCtrlRegs.PIEACK.all = PIEACK_GROUP7;
}


//
// ConfigureEPWM - Set up the ePWM2 module so that the A output has a period
//                 of 40us with a 50% duty. The SOCA signal is coincident with
//                 the rising edge of this.
//
void ConfigureEPWM(void)
{
    //
    // Make the timer count up with a period of 40us
    //
    EPwm2Regs.TBCTL.all = 0x0000;
    EPwm2Regs.TBPRD = 4000;

    //
    // Set the A output on zero and reset on CMPA
    //
    EPwm2Regs.AQCTLA.bit.ZRO = AQ_SET;
    EPwm2Regs.AQCTLA.bit.CAU = AQ_CLEAR;

    //
    // Set CMPA to 20us to get a 50% duty
    //
    EPwm2Regs.CMPA.bit.CMPA = 2000;

    //
    // Start ADC when timer equals zero (note: don't enable yet)
    //
    EPwm2Regs.ETSEL.bit.SOCASEL = ET_CTR_ZERO;
    EPwm2Regs.ETPS.bit.SOCAPRD =  ET_1ST;

    //
    // Enable initialization of the SOCA event counter. Since we are
    // disabling the ETSEL.SOCAEN bit, we need a way to reset the SOCACNT.
    // Hence, enable the counter initialize control.
    //
    EPwm2Regs.ETCNTINITCTL.bit.SOCAINITEN = 1;
}

//
// ConfigureADC - Write ADC configurations and power up the ADC for both
//                ADC A and ADC B
//
void ConfigureADC(void)
{
    EALLOW;

    //
    // Write prescale configurations
    //
    AdcaRegs.ADCCTL2.bit.PRESCALE = 6; // Set ADCCLK divider to /4
    AdcbRegs.ADCCTL2.bit.PRESCALE = 6;

    //
    // Set mode
    //
    AdcSetMode(ADC_ADCA, ADC_RESOLUTION_12BIT, ADC_SIGNALMODE_SINGLE);
    AdcSetMode(ADC_ADCB, ADC_RESOLUTION_12BIT, ADC_SIGNALMODE_SINGLE);

    //
    // Set pulse positions to late
    //
    AdcaRegs.ADCCTL1.bit.INTPULSEPOS = 1;
    AdcbRegs.ADCCTL1.bit.INTPULSEPOS = 1;

    //
    // Power up the ADC
    //
    AdcaRegs.ADCCTL1.bit.ADCPWDNZ = 1;
    AdcbRegs.ADCCTL1.bit.ADCPWDNZ = 1;

    //
    // Delay for 1ms to allow ADCs time to power up
    //
    DELAY_US(1000);

    EDIS;
}

//
// SetupADCContinuous - setup the ADC to continuously convert on one channel
//
void SetupADCContinuous(volatile struct ADC_REGS * adcRegs, Uint16 channel)
{
    Uint16 acqps;

    //
    // Determine minimum acquisition window (in SYSCLKS) based on resolution
    //
    if(ADC_RESOLUTION_12BIT == AdcaRegs.ADCCTL2.bit.RESOLUTION)
    {
        acqps = 14; // 75ns
    }
    else // Resolution is 16-bit
    {
        acqps = 63; // 320ns
    }

    EALLOW;

    //
    // SOCs will convert on same specified channel
    //
    adcRegs->ADCSOC0CTL.bit.CHSEL  = channel;
    adcRegs->ADCSOC1CTL.bit.CHSEL  = channel;
    adcRegs->ADCSOC2CTL.bit.CHSEL  = channel;
    adcRegs->ADCSOC3CTL.bit.CHSEL  = channel;
    adcRegs->ADCSOC4CTL.bit.CHSEL  = channel;
    adcRegs->ADCSOC5CTL.bit.CHSEL  = channel;
    adcRegs->ADCSOC6CTL.bit.CHSEL  = channel;
    adcRegs->ADCSOC7CTL.bit.CHSEL  = channel;
    adcRegs->ADCSOC8CTL.bit.CHSEL  = channel;
    adcRegs->ADCSOC9CTL.bit.CHSEL  = channel;
    adcRegs->ADCSOC10CTL.bit.CHSEL = channel;
    adcRegs->ADCSOC11CTL.bit.CHSEL = channel;
    adcRegs->ADCSOC12CTL.bit.CHSEL = channel;
    adcRegs->ADCSOC13CTL.bit.CHSEL = channel;
    adcRegs->ADCSOC14CTL.bit.CHSEL = channel;
    adcRegs->ADCSOC15CTL.bit.CHSEL = channel;

    //
    // Sample window is acqps + 1 SYSCLK cycles
    //
    adcRegs->ADCSOC0CTL.bit.ACQPS  = acqps;
    adcRegs->ADCSOC1CTL.bit.ACQPS  = acqps;
    adcRegs->ADCSOC2CTL.bit.ACQPS  = acqps;
    adcRegs->ADCSOC3CTL.bit.ACQPS  = acqps;
    adcRegs->ADCSOC4CTL.bit.ACQPS  = acqps;
    adcRegs->ADCSOC5CTL.bit.ACQPS  = acqps;
    adcRegs->ADCSOC6CTL.bit.ACQPS  = acqps;
    adcRegs->ADCSOC7CTL.bit.ACQPS  = acqps;
    adcRegs->ADCSOC9CTL.bit.ACQPS  = acqps;
    adcRegs->ADCSOC10CTL.bit.ACQPS = acqps;
    adcRegs->ADCSOC11CTL.bit.ACQPS = acqps;
    adcRegs->ADCSOC12CTL.bit.ACQPS = acqps;
    adcRegs->ADCSOC13CTL.bit.ACQPS = acqps;
    adcRegs->ADCSOC14CTL.bit.ACQPS = acqps;
    adcRegs->ADCSOC15CTL.bit.ACQPS = acqps;

    //
    // Trigger SCO0 from EPWM2SOCA
    //
    adcRegs->ADCSOC0CTL.bit.TRIGSEL = 7;

    //
    // Trigger all other SOCs from INT1 (EOC on SOC0)
    //
    adcRegs->ADCINTSOCSEL1.bit.SOC1 = 1;
    adcRegs->ADCINTSOCSEL1.bit.SOC2 = 1;
    adcRegs->ADCINTSOCSEL1.bit.SOC3 = 1;
    adcRegs->ADCINTSOCSEL1.bit.SOC4 = 1;
    adcRegs->ADCINTSOCSEL1.bit.SOC5 = 1;
    adcRegs->ADCINTSOCSEL1.bit.SOC6 = 1;
    adcRegs->ADCINTSOCSEL1.bit.SOC7 = 1;
    adcRegs->ADCINTSOCSEL2.bit.SOC8 = 1;
    adcRegs->ADCINTSOCSEL2.bit.SOC9 = 1;
    adcRegs->ADCINTSOCSEL2.bit.SOC10 = 1;
    adcRegs->ADCINTSOCSEL2.bit.SOC11 = 1;
    adcRegs->ADCINTSOCSEL2.bit.SOC12 = 1;
    adcRegs->ADCINTSOCSEL2.bit.SOC13 = 1;
    adcRegs->ADCINTSOCSEL2.bit.SOC14 = 1;
    adcRegs->ADCINTSOCSEL2.bit.SOC15 = 1;

    adcRegs->ADCINTSEL1N2.bit.INT1E = 1;    // Enable INT1 flag
    adcRegs->ADCINTSEL1N2.bit.INT2E = 1;    // Enable INT2 flag
    adcRegs->ADCINTSEL3N4.bit.INT3E = 0;    // Disable INT3 flag
    adcRegs->ADCINTSEL3N4.bit.INT4E = 0;    // Disable INT4 flag

    adcRegs->ADCINTSEL1N2.bit.INT1CONT = 1;
    adcRegs->ADCINTSEL1N2.bit.INT2CONT = 1;

    adcRegs->ADCINTSEL1N2.bit.INT1SEL = 0;  // End of SOC0
    adcRegs->ADCINTSEL1N2.bit.INT2SEL = 15; // End of SOC15

    EDIS;
}

//
// DMAInit - Initialize DMA ch 1 to transfer ADCA results and DMA ch 2 to
//           transfer ADCB results
//
void DMAInit(void)
{
    //
    // Initialize DMA
    //
    DMAInitialize();

    //
    // DMA set up for first ADC
    //
    DMACH1AddrConfig(adcData0, &AdcaResultRegs.ADCRESULT0);

    //
    // Perform enough 16-word bursts to fill the results buffer. Data will be
    // transferred 32 bits at a time hence the address steps below.
    //
    // Enable the DMA channel 1 interrupt
    //
    DMACH1BurstConfig(15, 2, 2);
    DMACH1TransferConfig((RESULTS_BUFFER_SIZE >> 4) - 1, -14, 2);
    DMACH1ModeConfig(
                        DMA_ADCAINT2,
                        PERINT_ENABLE,
                        ONESHOT_DISABLE,
                        CONT_DISABLE,
                        SYNC_DISABLE,
                        SYNC_SRC,
                        OVRFLOW_DISABLE,
                        THIRTYTWO_BIT,
                        CHINT_END,
                        CHINT_ENABLE
                    );

    //
    // DMA set up for second ADC
    //
    DMACH2AddrConfig(adcData1, &AdcbResultRegs.ADCRESULT0);

    //
    // Perform enough 16-word bursts to fill the results buffer. Data will be
    // transferred 32 bits at a time hence the address steps below.
    //
    DMACH2BurstConfig(15, 2, 2);
    DMACH2TransferConfig((RESULTS_BUFFER_SIZE >> 4) - 1, -14, 2);
    DMACH2ModeConfig(
                        DMA_ADCAINT2,
                        PERINT_ENABLE,
                        ONESHOT_DISABLE,
                        CONT_DISABLE,
                        SYNC_DISABLE,
                        SYNC_SRC,
                        OVRFLOW_DISABLE,
                        THIRTYTWO_BIT,
                        CHINT_END,
                        CHINT_DISABLE
                    );
}

//
// End of file
//

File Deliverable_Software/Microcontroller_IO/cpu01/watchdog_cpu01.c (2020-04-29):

//
// Included Files
//
#include "F28x_Project.h"
#include "math.h"
#include "F2837xS_dma.h"
//
// Function Prototypes
//
interrupt void AdcISR(void);
extern void DelayUs(Uint16);
//
// Defines
#define pi 3.14159265
//
// Globals

float32 Vref = 3.0;
float32 Vmea = 0.0;
Uint32 count = 0;
float32 Vcmd = 2.1;
float32 Vfilt = 2.0;
float32 Vufilt = 2.1;
Uint32 t = 0;

float32 first = 1000.0;
float32 second = 1500.0;
float32 third = 2550.0;
float32 fourth = 5000.0;
float32 T = 1.0/25000.0;
float32 gain = 0.0;
float32 g = 50.0;
float32 firstC;
float32 secondC;
float32 secondC2;
float32 thirdC;
float32 thirdC2;
float32 fifthC;
float32 fifthC2;
float32 fs = 25000.0;
int k = 0;
float32 kk = 0.0;
float32 gainArray[100];


void main(void)
{
    DINT; //Disable Interrupts
    EALLOW; //Macro for enabling writing to protected registers
    WdRegs.WDCR.all = 0b0000000001101000;//Setting bit 6 to 1 disables the watchdog. to write successfully, bits 3-5 must be 1,0,1, respectively
    //setting clock rate manually: [2.7.6.2] modified for class
    ClkCfgRegs.CLKSRCCTL1.bit.OSCCLKSRCSEL = 0;// INTOSC2 fosc = 10 MHz
    ClkCfgRegs.SYSPLLCTL1.bit.PLLCLKEN = 0; //Bypass PLL until Steady State is Achieved
    ClkCfgRegs.SYSCLKDIVSEL.all = 0b0;//Want division by 1
    ClkCfgRegs.SYSPLLMULT.all = 20; // want 200MHz, multiply by 20
    while(ClkCfgRegs.SYSPLLSTS.bit.LOCKS != 1); // Do NOTHING until LOCKS is 1, meaning Steady State is achieved
    ClkCfgRegs.SYSCLKDIVSEL.all = 0+1; // Add 1 to SYSCLKDIVSEL Register before switching to PLL, so as to prevent issues w/current
    ClkCfgRegs.SYSPLLCTL1.bit.PLLCLKEN = 1; //Switch to Phase Locked Loop (PLL)
    ClkCfgRegs.SYSCLKDIVSEL.all = 0; //Set DIVSEL back to normal

    //Set the Timer scale factor [2.15.2.3]
    CpuTimer0Regs.TCR.bit.TSS = 0x1; //stop the timer by writing 1
    CpuTimer0Regs.TCR.bit.TRB = 0x1; //load the timer by writing 1
    CpuTimer0Regs.TCR.bit.TIE = 0x1; //enable interrupt by writing 1. Every timer period sends an interrupt.
    CpuTimer0Regs.PRD.all = 7999; // set the scale factor to 8000 (PRD + 1) ftmr = 25kHz

    //Enable and register ADC interrupts with the PIE system
    PieCtrlRegs.PIECTRL.bit.ENPIE = 1; //Set ENPIE to 1 to enable peripheral interrupts
    IER = 0b1; //Enabling proper group for CPU-Level Interrupts [CPU Instruction Set 3.2.2]
    PieVectTable.ADCA1_INT = &AdcISR; //Putting the address of the ISR into the Vector Table [See Lab 3 Sec. 2.2.1]
    PieCtrlRegs.PIEIER1.bit.INTx1 = 1; // use Table 2-2 in Tech Ref Manual to find ADCA4 PIE Designation

    //Initialize DAC Registers
    CpuSysRegs.PCLKCR16.bit.DAC_A = 1; //Turn on DAC Clock
    asm(" NOP"); asm(" NOP"); //2 NOPs for Delay
    DacaRegs.DACCTL.bit.DACREFSEL = 1; //Select DAC Module ref voltage VREFHI [11.4.2.2]
    DacaRegs.DACOUTEN.bit.DACOUTEN = 1; //Enable DAC module output on bit 0
    DacaRegs.DACVALS.all = 4096.0*Vcmd/Vref; // Set Initial Value to 4096 * (Vcmd/Vref); Vcmd = Vin at t=0;
    //For Pin J 3-9 (DACB)
    CpuSysRegs.PCLKCR16.bit.DAC_B = 1; //Turn on DAC Clock
     asm(" NOP"); asm(" NOP"); //2 NOPs for Delay
    DacbRegs.DACCTL.bit.DACREFSEL = 1;
    DacbRegs.DACOUTEN.bit.DACOUTEN = 1;
    DacbRegs.DACVALS.all = 4096.0*Vfilt/Vref;


    //Initialize ADC Registers
    CpuSysRegs.PCLKCR13.bit.ADC_A = 0b1; //turn ON ADC module clock signal [2.15.11.17]
    asm(" NOP"); asm(" NOP");
    AdcaRegs.ADCCTL2.bit.PRESCALE = 0b0110; //set internal clock frequency to 1/4 fclk,cpu [10.4.2.2]
    AdcaRegs.ADCCTL1.bit.ADCPWDNZ = 1; //power up analog power supply [10.4.2.1]
    DelayUs(500);
    //configure the ADC conversions [10.4.2.18]
    AdcaRegs.ADCSOC1CTL.bit.TRIGSEL = 0x1; //define trigger source as CPU1 Timer0 (see definition above)
    AdcaRegs.ADCSOC1CTL.bit.CHSEL = 0x4; //define input pin for ADCIN4 (J7-9)
    AdcaRegs.ADCSOC1CTL.bit.ACQPS = 39;  //System Clock is 5ns wide. ADC ACq. time is 200ns. This is 40 clock cycles, meaning this value is 39 [Table 10-31]

   //For Pin J7-4 (ADCINA2):

    AdcaRegs.ADCSOC2CTL.bit.TRIGSEL = 0x1; //define trigger source as CPU1 Timer0 (see definition above)
    AdcaRegs.ADCSOC2CTL.bit.CHSEL = 0x2; //define input pin for (J7-4)
    AdcaRegs.ADCSOC2CTL.bit.ACQPS = 39;  //System Clock is 5ns wide. ADC ACq. time is 200ns. This is 40 clock cycles, meaning this value is 39 [Table 10-31]

    //configure and enable the interrupts
    AdcaRegs.ADCCTL1.bit.INTPULSEPOS = 0b1; //ADC Interrupt Pulse Position occurs at EOC [10.4.2.1]
    AdcaRegs.ADCINTSEL1N2.bit.INT1SEL = 0x2; //Set trigger for ADCINT2 to EOC2 [10.4.2.9]
    AdcaRegs.ADCINTSEL1N2.bit.INT1E = 0b1; //enable ADCINT1 at EOC


    CpuTimer0Regs.TCR.bit.TSS = 0x0; //start the timer by writing 0
    WdRegs.WDCR.all = 0b0000000000101000; // writing 0 to bit 6, enabling watchdog timer
    EDIS;//Macro for disabling writing to protected registers
    EINT;   //Globally enable CPU interrupts
    while(1) {
        EALLOW; //SERVICING THE TIMER
        WdRegs.WDKEY.all = 0x0055;
        WdRegs.WDKEY.all = 0x00AA; //disabling counter
        EDIS;
    }
}
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

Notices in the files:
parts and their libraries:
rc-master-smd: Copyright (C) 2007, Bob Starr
